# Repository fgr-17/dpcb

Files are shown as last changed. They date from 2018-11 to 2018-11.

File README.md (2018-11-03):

# VOP24_LPCXpresso1769_baseHW #

### autor: Ing. Roux Federico G. (rouxfederico@gmail.com) ###

Desarrollo en KICAD del hardware base para LPCXpresso1769 con los componentes básicos:

	- regulación de tensión digital y analógica.
	- ads1292
	- slot microSD
	- salida serie para BT
	- medición de batería

## Historial ##

27.06.2018:

	- Creación del repositorio
    - se inicio el esquematico con dos reg mc1702, micro sd y medicion de bateria con lm358
    ...
    - se agrego simbolo del lpcxpresso1769
    - falta acomodar los directorios de las librerias
    - falta ads1292, simbolo y footprint
    - falta footprint lpcxpresso1769

29.06.2018:

    - conexiones con la SD y lpc1796
    - falta ads1292, simbolo y footprint
    - falta footprint lpcxpresso1769

30.06.2018:

    - se agrego simbolo ads1292 al esquematico
    - falta terminar las conexiones del ads
    - conviene separar en modulos jerarq. -> VER COMO SE HACE

PENDIENTES:

- ver modelo del diodo schottky del L4411
- ver footprint del micro USB B - ver con lo q consiga
- definir inductor acoplado - HECHO
- intercambiar pines TPD_EN y USB_ID para que quede para rutear directo

02/11/2018 :

   - intercambiado pines TPD_EN y USB_ID para que quede para rutear directo
   - cambio de footprint de J303 y J302 por tira de pines de 2.54mm

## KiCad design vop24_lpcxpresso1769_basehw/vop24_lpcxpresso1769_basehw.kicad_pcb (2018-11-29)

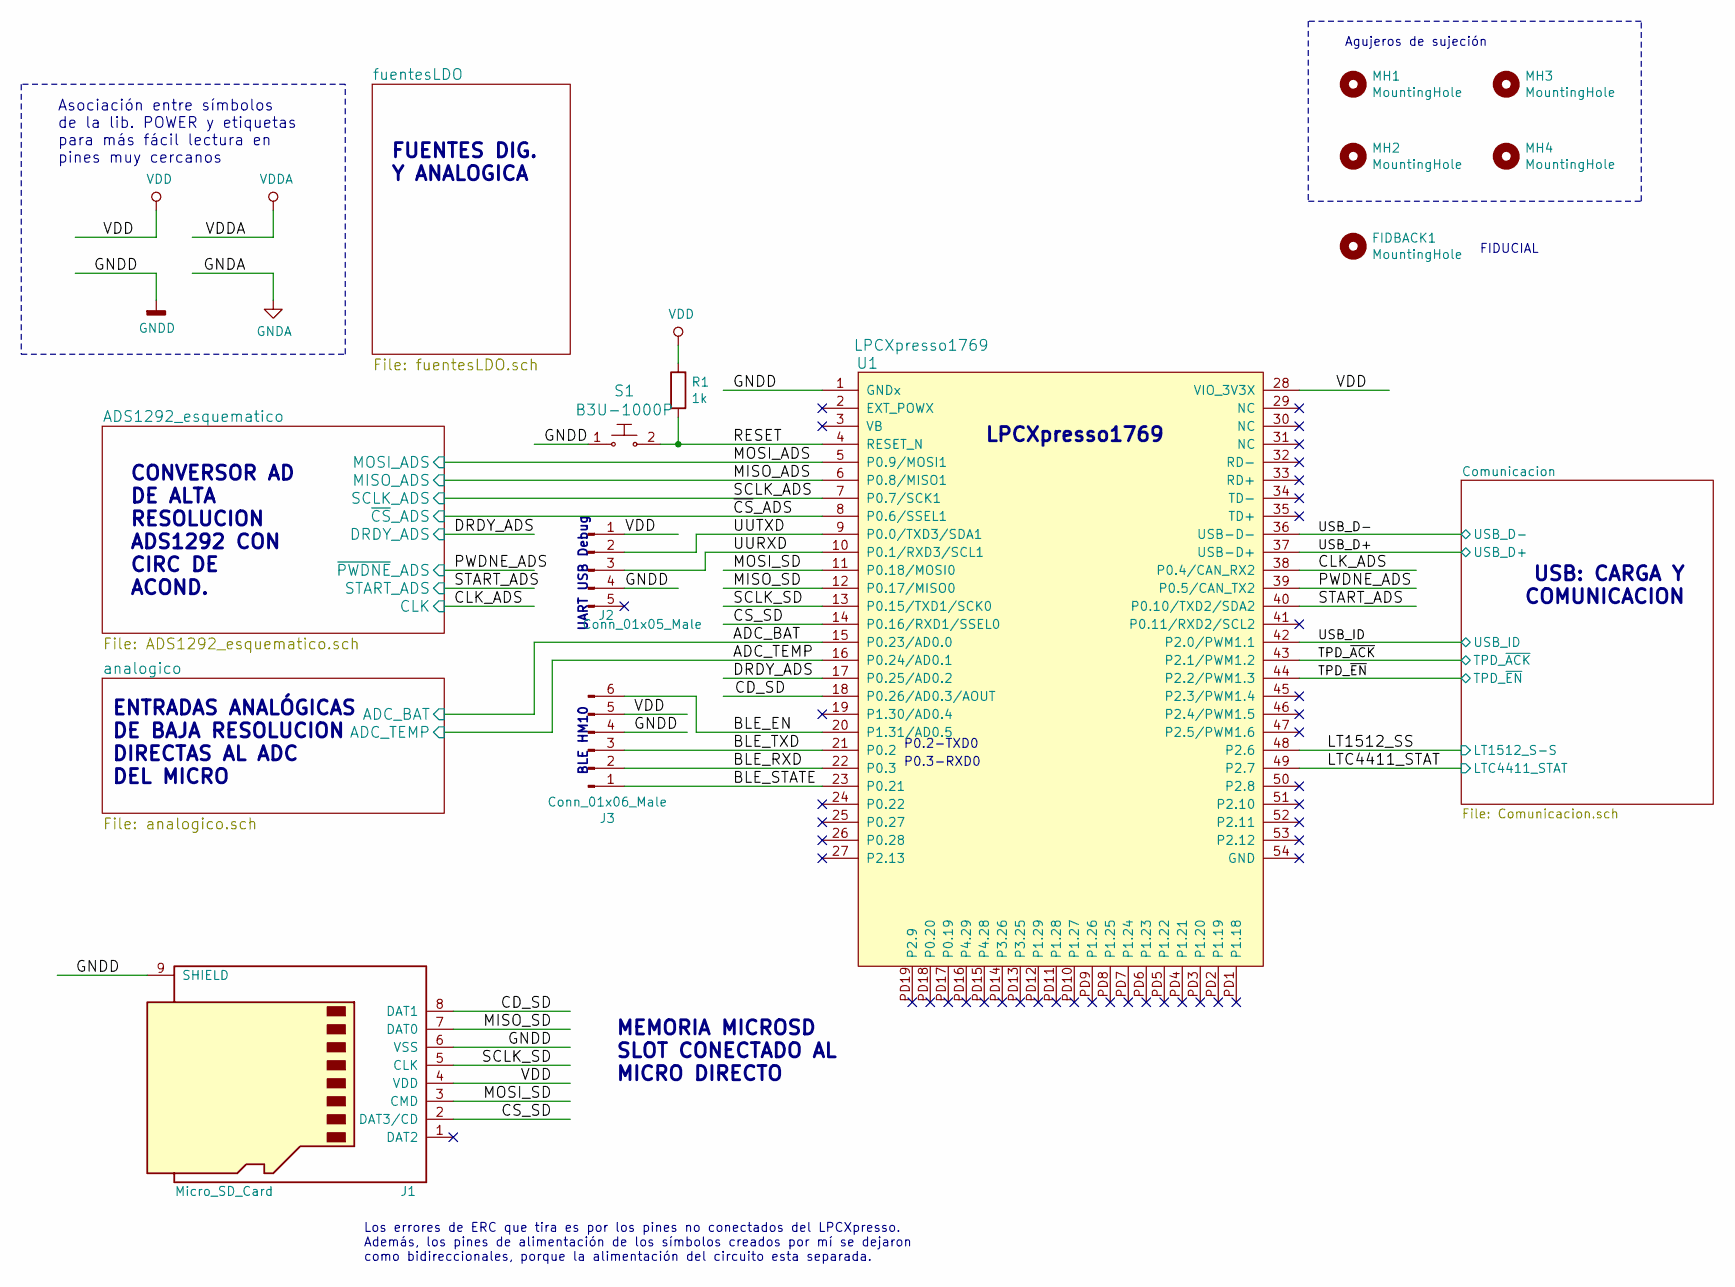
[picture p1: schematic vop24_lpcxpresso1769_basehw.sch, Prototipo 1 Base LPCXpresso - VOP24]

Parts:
FIDBACK1: MountingHole; Fiducial_0.75mm_Dia_1.5mm_Outer
J1: Micro_SD_Card; microSD_3020-901-0001-ACH-ELECTRONICS
J2: Conn_01x05_Male; PinSocket_1x05_P2.54mm_Vertical
J3: Conn_01x06_Male; PinSocket_1x06_P2.54mm_Vertical
MH1, MH2, MH3, MH4: MountingHole; MountingHole_3.5mm
R1: 1k; R_0805_2012Metric_Pad1.15x1.40mm_HandSolder
S1: B3U-1000P; Switch_Tactile_SMD_B3U-1000P; MPN B3U-1000P; Digi-Key_PN SW1020CT-ND
U1: LPCXpresso1769

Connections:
/ADC_BAT: U1.15 (P0.23/AD0.0); also elsewhere on the board
/ADC_TEMP: U1.16 (P0.24/AD0.1); also elsewhere on the board
/BLE_EN: J3.6, U1.20 (P1.31/AD0.5)
/BLE_RXD: J3.2, U1.22 (P0.3)
/BLE_STATE: J3.1, U1.23 (P0.21)
/BLE_TXD: J3.3, U1.21 (P0.2)
/CD_SD: J1.8 (DAT1), U1.18 (P0.26/AD0.3/AOUT)
/CLK_ADS: U1.38 (P0.4/CAN_RX2); also elsewhere on the board
/CS_SD: J1.2 (DAT3/CD), U1.14 (P0.16/RXD1/SSEL0)
/DRDY_ADS: U1.17 (P0.25/AD0.2); also elsewhere on the board
/LT1512_SS: U1.48 (P2.6); also elsewhere on the board
/LTC4411_STAT: U1.49 (P2.7); also elsewhere on the board
/MISO_ADS: U1.6 (P0.8/MISO1); also elsewhere on the board
/MISO_SD: J1.7 (DAT0), U1.12 (P0.17/MISO0)
/MOSI_ADS: U1.5 (P0.9/MOSI1); also elsewhere on the board
/MOSI_SD: J1.3 (CMD), U1.11 (P0.18/MOSI0)
/PWDNE_ADS: U1.39 (P0.5/CAN_TX2); also elsewhere on the board
/RESET: R1.2, S1.2, U1.4 (RESET_N)
/SCLK_ADS: U1.7 (P0.7/SCK1); also elsewhere on the board
/SCLK_SD: J1.5 (CLK), U1.13 (P0.15/TXD1/SCK0)
/START_ADS: U1.40 (P0.10/TXD2/SDA2); also elsewhere on the board
/TPD_~ACK: U1.43 (P2.1/PWM1.2); also elsewhere on the board
/TPD_~EN: U1.44 (P2.2/PWM1.3); also elsewhere on the board
/USB_D+: U1.37 (USB-D+); also elsewhere on the board
/USB_D-: U1.36 (USB-D-); also elsewhere on the board
/USB_ID: U1.42 (P2.0/PWM1.1); also elsewhere on the board
/UURXD: J2.3, U1.10 (P0.1/RXD3/SCL1)
/UUTXD: J2.2, U1.9 (P0.0/TXD3/SDA1)
/~CS~_ADS: U1.8 (P0.6/SSEL1); also elsewhere on the board
GNDD: J1.6 (VSS), J1.9 (SHIELD), J2.4, J3.4, S1.1, U1.1 (GNDx); also elsewhere on the board
VDD: J1.4 (VDD), J2.1, J3.5, R1.1, U1.28 (VIO_3V3X); also elsewhere on the board

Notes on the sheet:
P0.2-TXD0
P0.3-RXD0
FUENTES DIG. Y ANALOGICA
ENTRADAS ANALÓGICAS DE BAJA RESOLUCION DIRECTAS AL ADC DEL MICRO
MEMORIA MICROSD SLOT CONECTADO AL MICRO DIRECTO
USB: CARGA Y COMUNICACION
CONVERSOR AD DE ALTA RESOLUCION ADS1292 CON CIRC DE ACOND.
LPCXpresso1769
Los errores de ERC que tira es por los pines no conectados del LPCXpresso. Además, los pines de alimentación de los símbolos creados por mí se dejaron como bidireccionales, porque la alimentación del circuito esta separada.
BLE HM10
UART USB Debug
Asociación entre símbolos de la lib. POWER y etiquetas para más fácil lectura en pines muy cercanos
Agujeros de sujeción
FIDUCIAL

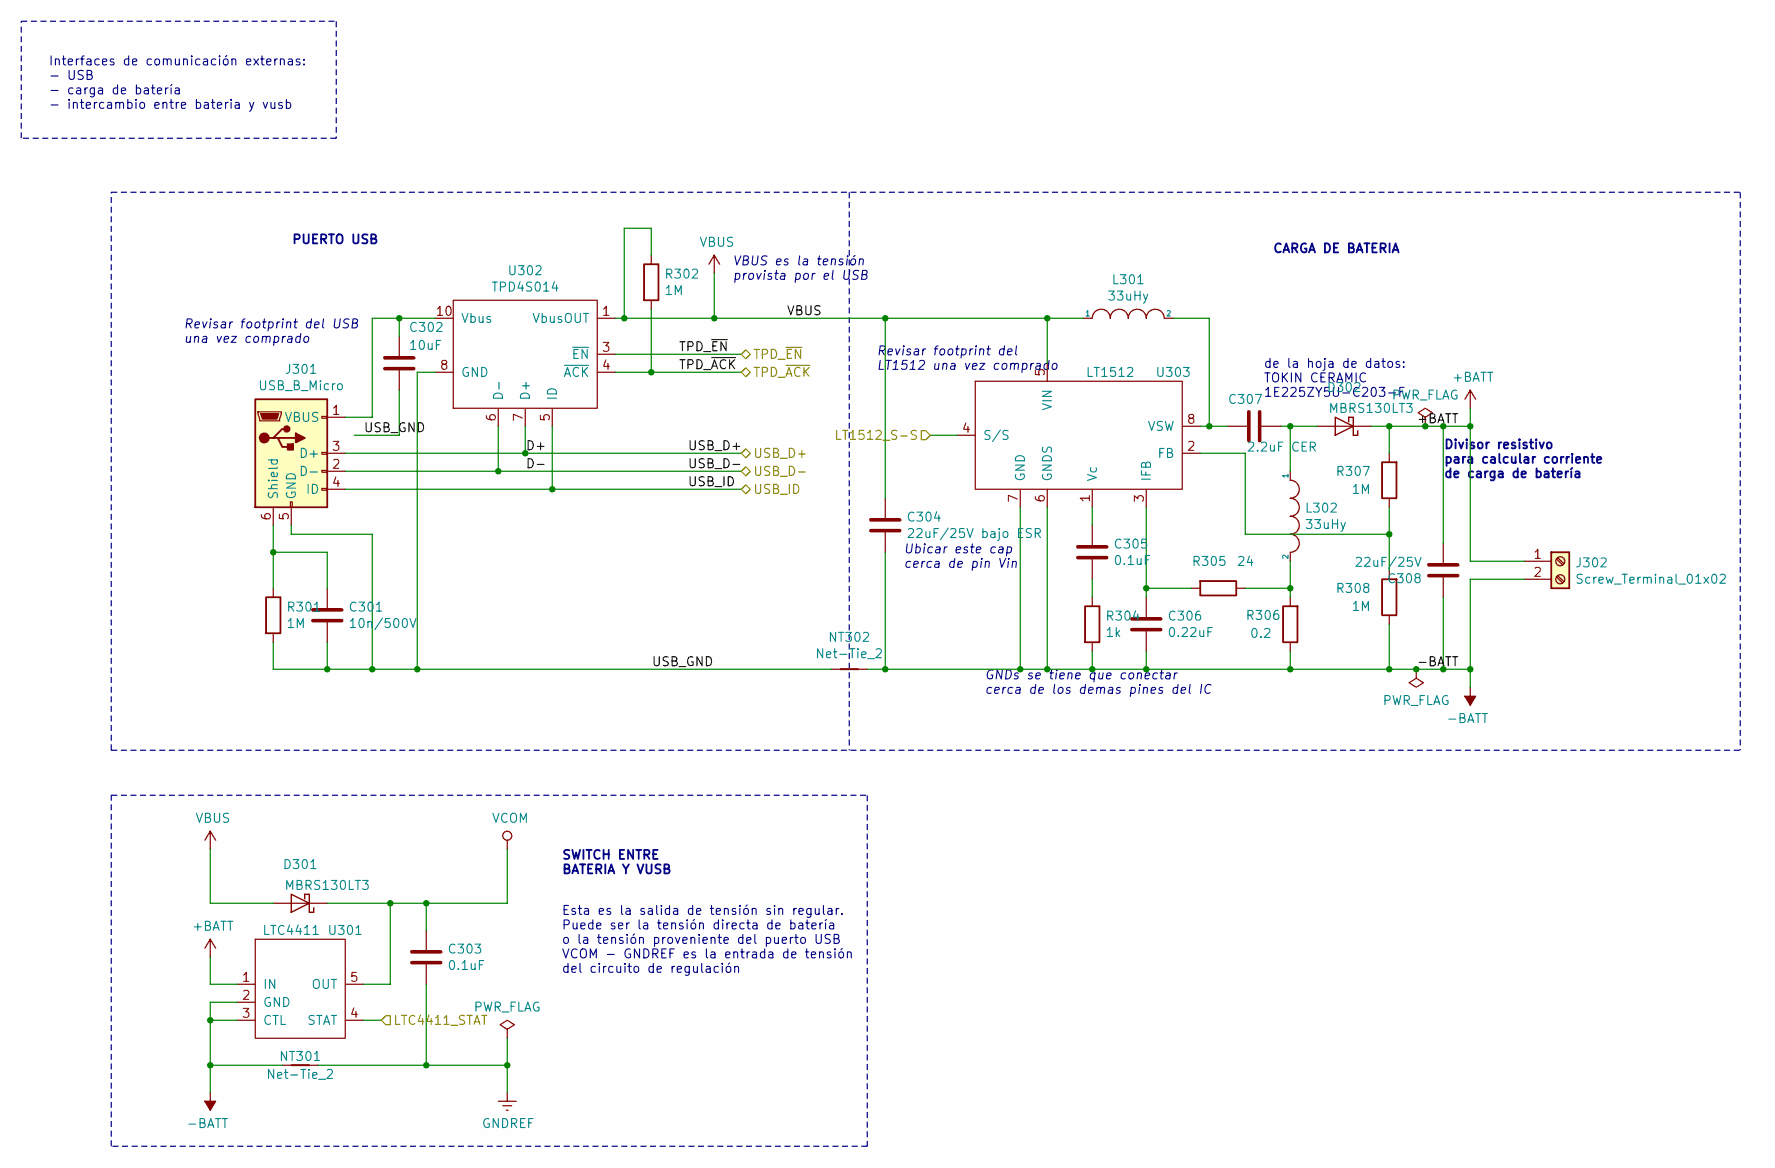
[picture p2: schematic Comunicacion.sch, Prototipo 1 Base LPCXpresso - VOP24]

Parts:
C301: 10n/500V; C_0805_2012Metric_Pad1.15x1.40mm_HandSolder
C302: 10uF; C_0805_2012Metric_Pad1.15x1.40mm_HandSolder
C303, C305: 0.1uF; C_0805_2012Metric_Pad1.15x1.40mm_HandSolder
C304: 22uF/25V bajo ESR; CP_Radial_D5.0mm_P2.50mm
C306: 0.22uF; C_0805_2012Metric_Pad1.15x1.40mm_HandSolder
C307: 2.2uF CER; CP_Radial_D5.0mm_P2.50mm
C308: 22uF/25V; CP_Radial_D5.0mm_P2.50mm
D301, D302: MBRS130LT3; D_SMB-SMC_Universal_Handsoldering
J301: USB_B_Micro; USB_Mini-B_Lumberg_2486_01_Horizontal
J302: Screw_Terminal_01x02; TerminalBlock_bornier-2_P5.08mm
L301, L302: 33uHy; L_Radial_D8.7mm_P5.00mm_Fastron_07HCP
NT301, NT302: Net-Tie_2; NetTie-2_SMD_Pad0.5mm
R301, R302, R307, R308: 1M; R_0805_2012Metric_Pad1.15x1.40mm_HandSolder
R304: 1k; R_0805_2012Metric_Pad1.15x1.40mm_HandSolder
R305: 24; R_0805_2012Metric_Pad1.15x1.40mm_HandSolder
R306: 0.2; R_0805_2012Metric_Pad1.15x1.40mm_HandSolder
U301: LTC4411; SOT-23-5_HandSoldering
U302: TPD4S014; Texas_R-PWSON-N10
U303: LT1512; SO-8_5.3x6.2mm_P1.27mm

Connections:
+BATT: C308.2, D302.1 (K), J302.1, R307.2, U301.1 (IN); also elsewhere on the board
-BATT: C304.2, C306.2, C308.1, J302.2, NT301.1, NT302.2, R304.2, R306.1, R308.1, U301.2 (GND), U301.3 (CTL), U303.6 (GNDS), U303.7 (GND); also elsewhere on the board
/Comunicacion/USB_GND: C301.2, C302.2, J301.5 (GND), NT302.1, R301.2, U302.8 (GND)
/LT1512_SS: U303.4 (S/S); also elsewhere on the board
/LTC4411_STAT: U301.4 (STAT); also elsewhere on the board
/TPD_~ACK: R302.2, U302.4 (~ACK); also elsewhere on the board
/TPD_~EN: U302.3 (~EN); also elsewhere on the board
/USB_D+: J301.3 (D+), U302.7 (D+); also elsewhere on the board
/USB_D-: J301.2 (D-), U302.6 (D-); also elsewhere on the board
/USB_ID: J301.4 (ID), U302.5 (ID); also elsewhere on the board
GNDREF: C303.2, NT301.2; also elsewhere on the board
unnamed: C301.1, J301.6 (Shield), R301.1
unnamed: C302.1, J301.1 (VBUS), U302.10 (Vbus)
unnamed: C305.1, U303.1 (Vc)
unnamed: C305.2, R304.1
unnamed: C306.1, R305.2, U303.3 (IFB)
unnamed: C307.1, D302.2 (A), L302.1
unnamed: C307.2, L301.2, U303.8 (VSW)
unnamed: L302.2, R305.1, R306.2
unnamed: R307.1, R308.2, U303.2 (FB)
VBUS: C304.1, D301.2 (A), L301.1, R302.1, U302.1 (VbusOUT), U303.5 (VIN)
VCOM: C303.1, D301.1 (K), U301.5 (OUT); also elsewhere on the board

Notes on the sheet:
de la hoja de datos: TOKIN CERAMIC 1E225ZY5U-C203-F
Divisor resistivo para calcular corriente de carga de batería
CARGA DE BATERIA
SWITCH ENTRE BATERIA Y VUSB
PUERTO USB
Revisar footprint del USB una vez comprado
Revisar footprint del LT1512 una vez comprado
Ubicar este cap cerca de pin Vin
GNDs se tiene que conectar cerca de los demas pines del IC
Interfaces de comunicación externas: - USB - carga de batería - intercambio entre bateria y vusb
Esta es la salida de tensión sin regular. Puede ser la tensión directa de batería o la tensión proveniente del puerto USB VCOM - GNDREF es la entrada de tensión del circuito de regulación
VBUS es la tensión provista por el USB

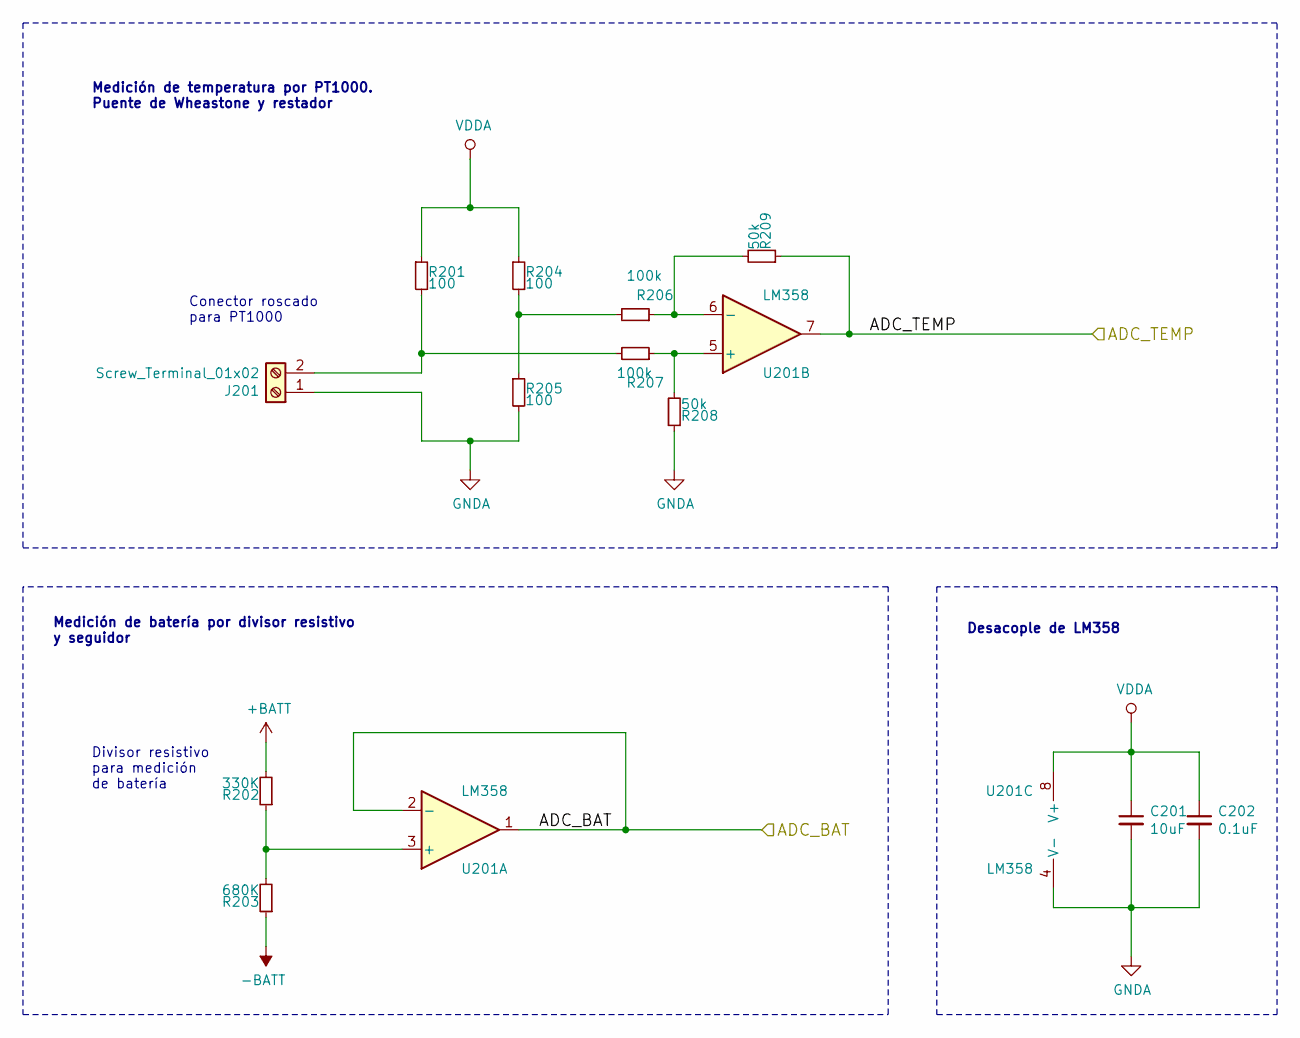
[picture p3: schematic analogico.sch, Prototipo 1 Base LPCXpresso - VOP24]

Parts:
C201: 10uF; C_0805_2012Metric_Pad1.15x1.40mm_HandSolder
C202: 0.1uF; C_0805_2012Metric_Pad1.15x1.40mm_HandSolder
J201: Screw_Terminal_01x02; TerminalBlock_bornier-2_P5.08mm
R201, R204, R205: 100; R_0805_2012Metric_Pad1.15x1.40mm_HandSolder
R202: 330K; R_0805_2012Metric_Pad1.15x1.40mm_HandSolder
R203: 680K; R_0805_2012Metric_Pad1.15x1.40mm_HandSolder
R206, R207: 100k; R_0805_2012Metric_Pad1.15x1.40mm_HandSolder
R208, R209: 50k; R_0805_2012Metric_Pad1.15x1.40mm_HandSolder
U201: LM358; SO-8_5.3x6.2mm_P1.27mm

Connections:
+BATT: R202.2; also elsewhere on the board
-BATT: R203.1; also elsewhere on the board
/ADC_BAT: U201.1, U201.2 (-); also elsewhere on the board
/ADC_TEMP: R209.1, U201.7; also elsewhere on the board
GNDA: C201.2, C202.2, J201.1, R205.2, R208.1, U201.4 (V-); also elsewhere on the board
unnamed: J201.2, R201.2, R207.2
unnamed: R202.1, R203.2, U201.3 (+)
unnamed: R204.2, R205.1, R206.2
unnamed: R206.1, R209.2, U201.6 (-)
unnamed: R207.1, R208.2, U201.5 (+)
VDDA: C201.1, C202.1, R201.1, R204.1, U201.8 (V+); also elsewhere on the board

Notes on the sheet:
Conector roscado para PT1000
Divisor resistivo para medición de batería
Medición de temperatura por PT1000. Puente de Wheastone y restador
Medición de batería por divisor resistivo y seguidor
Desacople de LM358

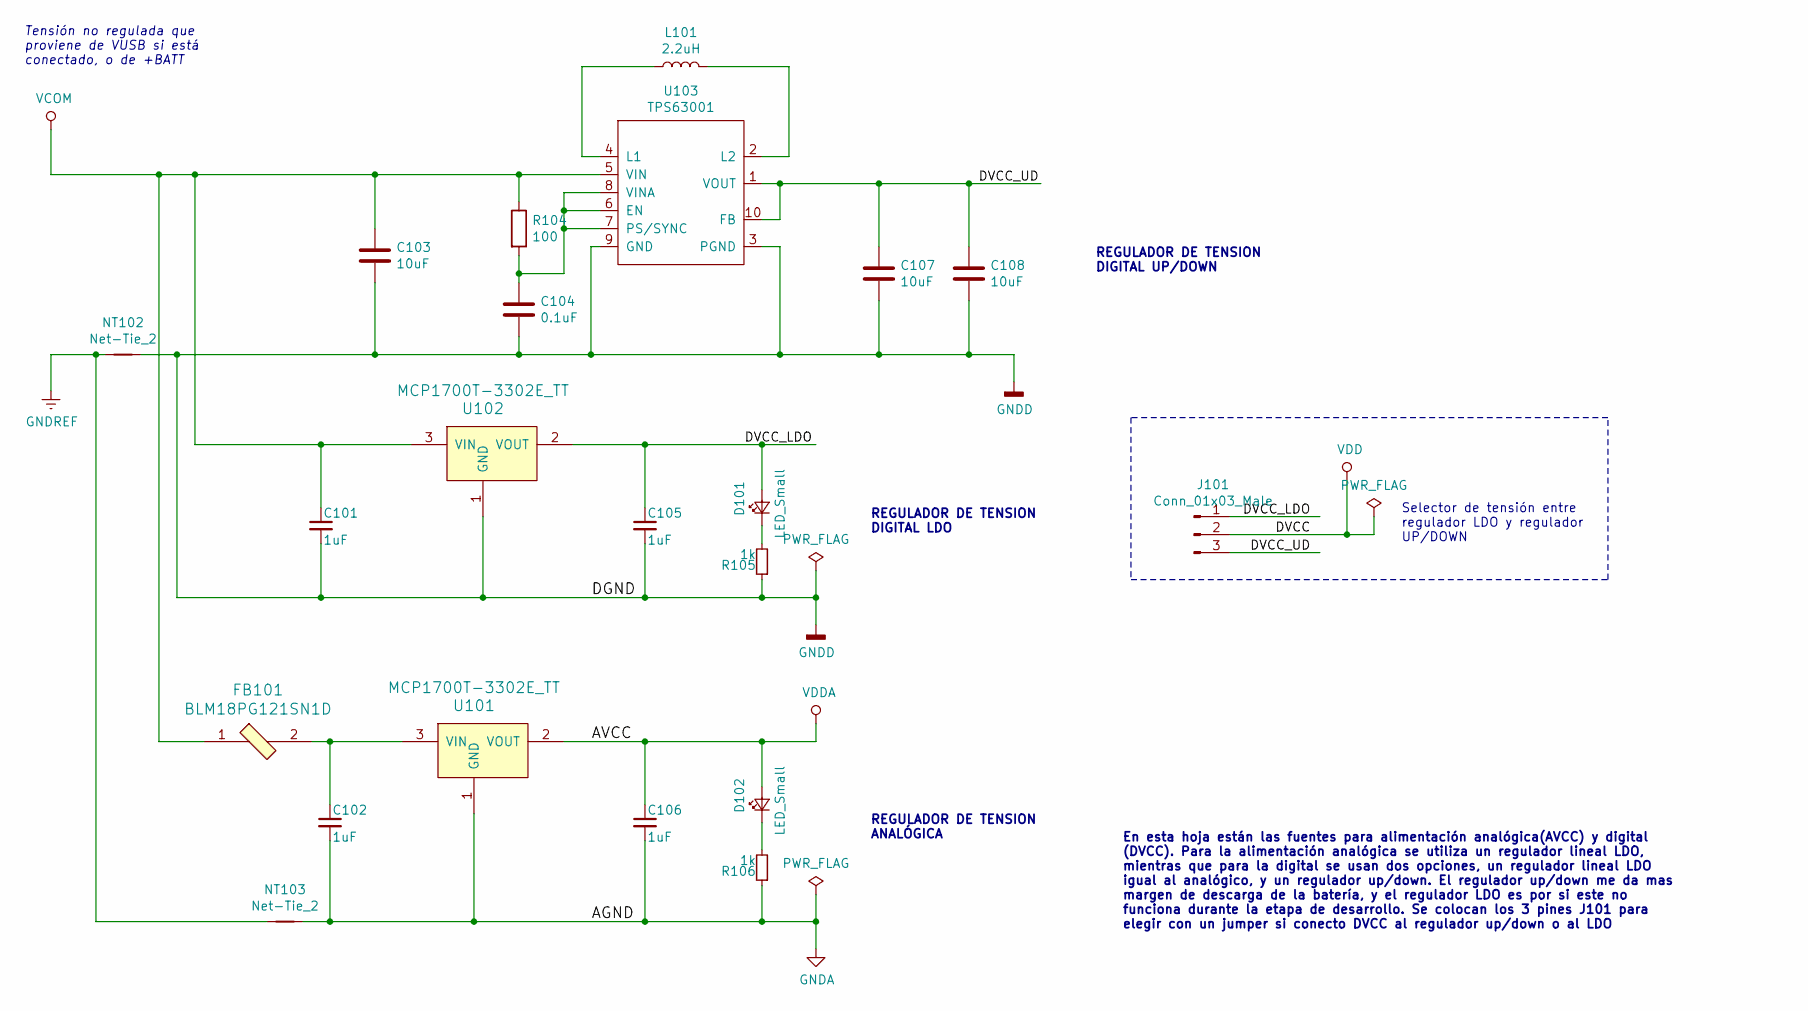
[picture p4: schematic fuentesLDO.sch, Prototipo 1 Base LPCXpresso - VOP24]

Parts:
C101, C102, C105, C106: 1uF; C_0805_2012Metric_Pad1.15x1.40mm_HandSolder
C103, C107, C108: 10uF; C_0805_2012Metric_Pad1.15x1.40mm_HandSolder
C104: 0.1uF; C_0805_2012Metric_Pad1.15x1.40mm_HandSolder
D101, D102: LED_Small; LED_0805_2012Metric_Pad1.15x1.40mm_HandSolder
FB101: BLM18PG121SN1D; 0603; MPN BLM18PG121SN1D; Digi-Key_PN 490-1037-1-ND
J101: Conn_01x03_Male; PinHeader_1x03_P2.54mm_Vertical
L101: 2.2uH; L_0805_2012Metric_Pad1.15x1.40mm_HandSolder
NT102, NT103: Net-Tie_2; NetTie-2_SMD_Pad0.5mm
R104: 100; R_0805_2012Metric_Pad1.15x1.40mm_HandSolder
R105, R106: 1k; R_0805_2012Metric_Pad1.15x1.40mm_HandSolder
U101, U102: MCP1700T-3302E_TT; SOT-23-3; MPN MCP1700T-3302E/TT; Digi-Key_PN MCP1700T3302ETTCT-ND
U103: TPS63001; VSON-10-1EP_3x3mm_P0.5mm_EP1.65x2.4mm_ThermalVias

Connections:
/fuentesLDO/DVCC_LDO: C105.1, D101.2 (A), J101.1, U102.2 (VOUT)
/fuentesLDO/DVCC_UD: C107.1, C108.1, J101.3, U103.1 (VOUT), U103.10 (FB)
GNDA: C102.2, C106.2, NT103.2, R106.1, U101.1 (GND); also elsewhere on the board
GNDD: C101.2, C103.2, C104.2, C105.2, C107.2, C108.2, NT102.2, R105.1, U102.1 (GND), U103.3 (PGND), U103.9 (GND); also elsewhere on the board
GNDREF: NT102.1, NT103.1; also elsewhere on the board
unnamed: C102.1, FB101.2, U101.3 (VIN)
unnamed: C104.1, R104.2, U103.6 (EN), U103.7 (PS/SYNC), U103.8 (VINA)
unnamed: D101.1 (K), R105.2
unnamed: D102.1 (K), R106.2
unnamed: L101.1, U103.4 (L1)
unnamed: L101.2, U103.2 (L2)
VCOM: C101.1, C103.1, FB101.1, R104.1, U102.3 (VIN), U103.5 (VIN); also elsewhere on the board
VDD: J101.2; also elsewhere on the board
VDDA: C106.1, D102.2 (A), U101.2 (VOUT); also elsewhere on the board

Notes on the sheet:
En esta hoja están las fuentes para alimentación analógica(AVCC) y digital (DVCC). Para la alimentación analógica se utiliza un regulador lineal LDO, mientras que para la digital se usan dos opciones, un regulador lineal LDO igual al analógico, y un regulador up/down. El regulador up/down me da mas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
Tensión no regulada que proviene de VUSB si está conectado, o de +BATT
REGULADOR DE TENSION ANALÓGICA
REGULADOR DE TENSION DIGITAL LDO
REGULADOR DE TENSION DIGITAL UP/DOWN
Selector de tensión entre regulador LDO y regulador UP/DOWN

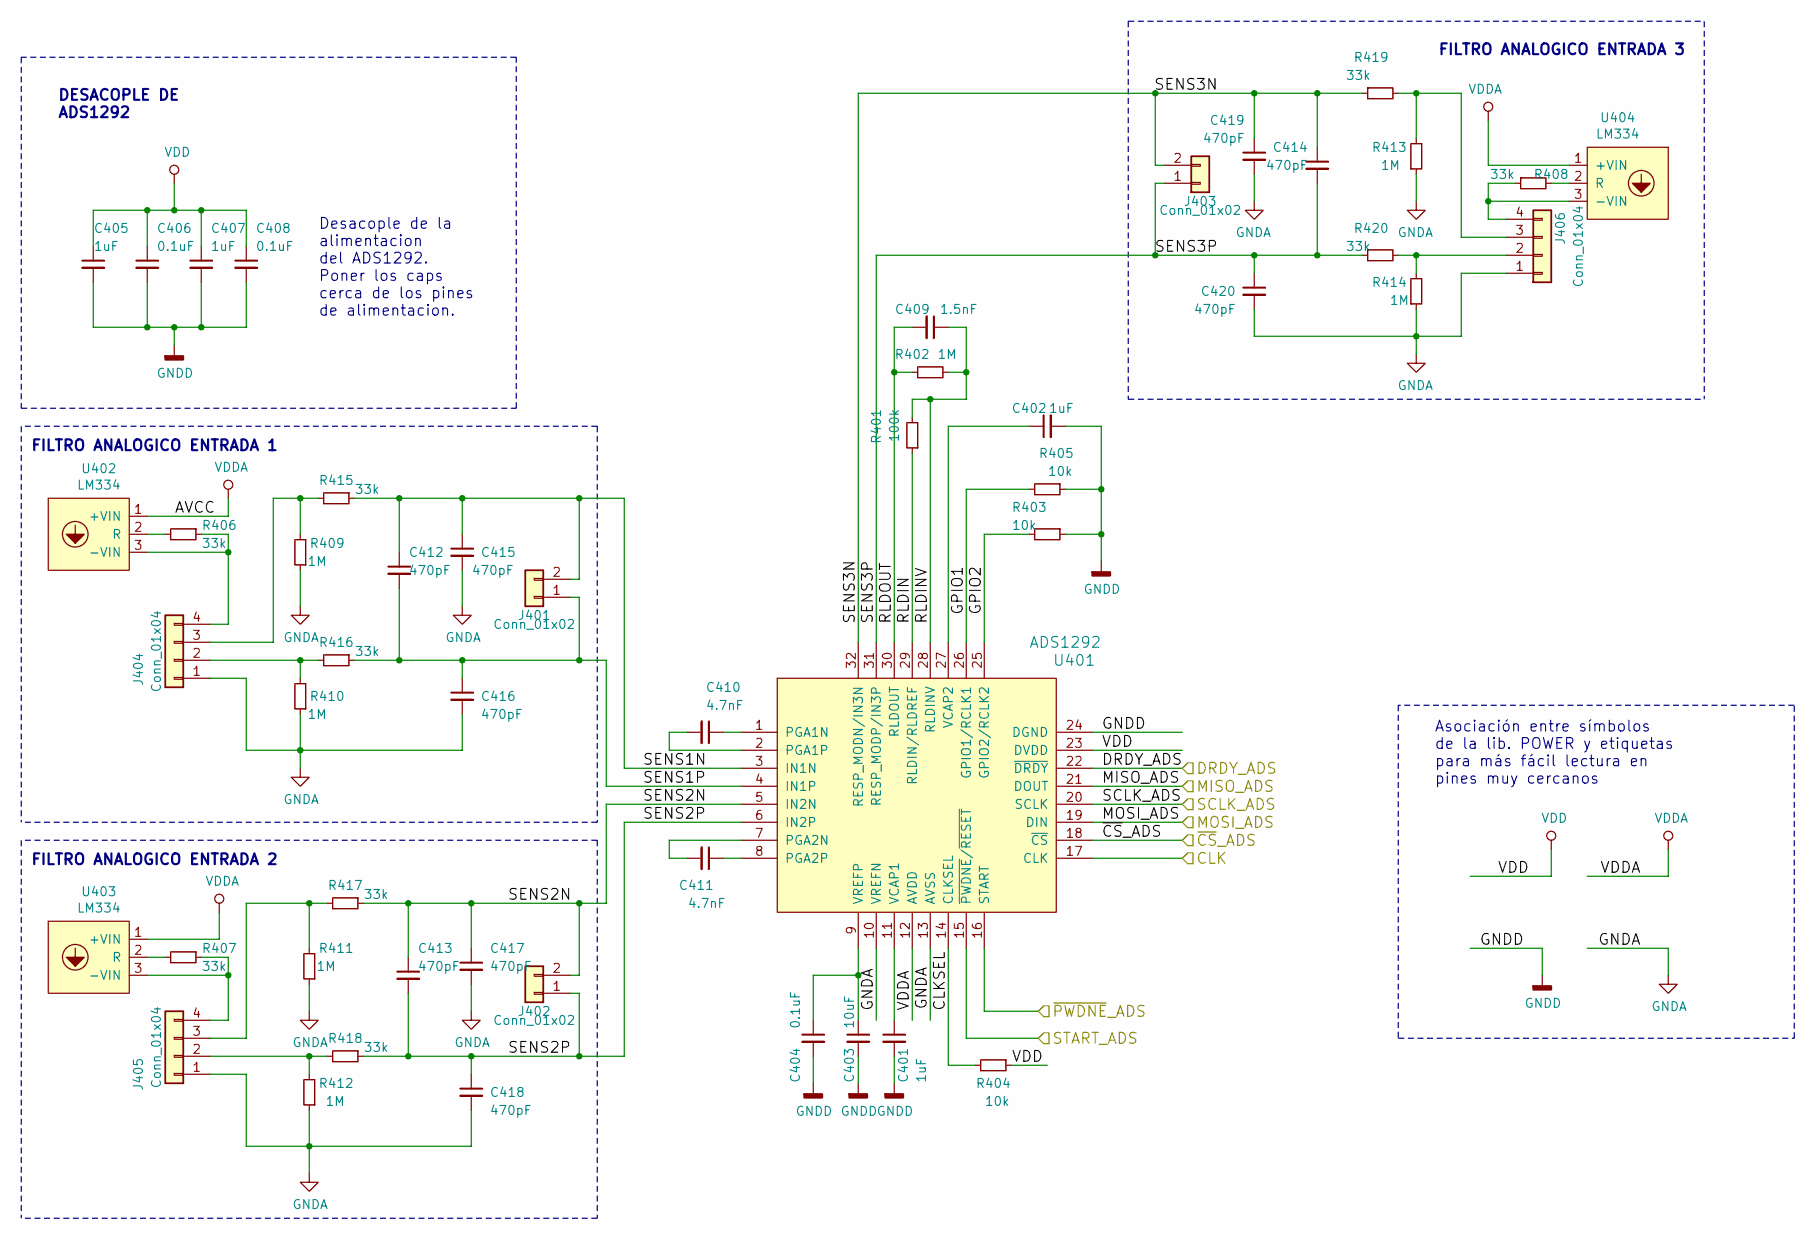
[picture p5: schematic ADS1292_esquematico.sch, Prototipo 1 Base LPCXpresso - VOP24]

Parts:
C401, C402, C405, C407: 1uF; C_0805_2012Metric_Pad1.15x1.40mm_HandSolder
C403: 10uF; C_0805_2012Metric_Pad1.15x1.40mm_HandSolder
C404, C406, C408: 0.1uF; C_0805_2012Metric_Pad1.15x1.40mm_HandSolder
C409: 1.5nF; C_0805_2012Metric_Pad1.15x1.40mm_HandSolder
C410, C411: 4.7nF; C_0805_2012Metric_Pad1.15x1.40mm_HandSolder
C412, C413, C414, C415, C416, C417, C418, C419, C420: 470pF; C_0805_2012Metric_Pad1.15x1.40mm_HandSolder
J401, J402, J403: Conn_01x02; PinHeader_1x02_P1.27mm_Vertical
J404, J405, J406: Conn_01x04; PinSocket_1x04_P2.54mm_Vertical
R401: 100k; R_0805_2012Metric_Pad1.15x1.40mm_HandSolder
R402, R409, R410, R411, R412, R413, R414: 1M; R_0805_2012Metric_Pad1.15x1.40mm_HandSolder
R403, R404, R405: 10k; R_0805_2012Metric_Pad1.15x1.40mm_HandSolder
R406, R407, R408, R415, R416, R417, R418, R419, R420: 33k; R_0805_2012Metric_Pad1.15x1.40mm_HandSolder
U401: ADS1292; PQFP-G32_7x7mm_P0.5mm
U402, U403, U404: LM334; TO-92_Inline_Wide

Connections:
/ADS1292_esquematico/CLKSEL: R404.2, U401.14 (CLKSEL)
/ADS1292_esquematico/GPIO1: R405.2, U401.26 (GPIO1/RCLK1)
/ADS1292_esquematico/GPIO2: R403.2, U401.25 (GPIO2/RCLK2)
/ADS1292_esquematico/RLDIN: R401.1, U401.29 (RLDIN/RLDREF)
/ADS1292_esquematico/RLDINV: C409.1, R401.2, R402.2, U401.28 (RLDINV)
/ADS1292_esquematico/RLDOUT: C409.2, R402.1, U401.30 (RLDOUT)
/ADS1292_esquematico/SENS1N: C412.1, C415.1, J401.2, R415.1, U401.3 (IN1N)
/ADS1292_esquematico/SENS1P: C412.2, C416.1, J401.1, R416.1, U401.4 (IN1P)
/ADS1292_esquematico/SENS2N: C413.1, C417.1, J402.2, R417.1, U401.5 (IN2N)
/ADS1292_esquematico/SENS2P: C413.2, C418.1, J402.1, R418.1, U401.6 (IN2P)
/ADS1292_esquematico/SENS3N: C414.1, C419.1, J403.2, R419.1, U401.32 (RESP_MODN/IN3N)
/ADS1292_esquematico/SENS3P: C414.2, C420.1, J403.1, R420.1, U401.31 (RESP_MODP/IN3P)
/CLK_ADS: U401.17 (CLK); also elsewhere on the board
/DRDY_ADS: U401.22 (~DRDY); also elsewhere on the board
/MISO_ADS: U401.21 (DOUT); also elsewhere on the board
/MOSI_ADS: U401.19 (DIN); also elsewhere on the board
/PWDNE_ADS: U401.16 (START); also elsewhere on the board
/SCLK_ADS: U401.20 (SCLK); also elsewhere on the board
/START_ADS: U401.15 (~PWDNE~/~RESET~); also elsewhere on the board
/~CS~_ADS: U401.18 (~CS); also elsewhere on the board
GNDA: C415.2, C416.2, C417.2, C418.2, C419.2, C420.2, J404.1, J405.1, J406.1, R409.1, R410.1, R411.1, R412.1, R413.1, R414.1, U401.10 (VREFN), U401.13 (AVSS); also elsewhere on the board
GNDD: C401.2, C402.2, C403.2, C404.2, C405.2, C406.2, C407.2, C408.2, R403.1, R405.1, U401.24 (DGND); also elsewhere on the board
unnamed: C401.1, U401.11 (VCAP1)
unnamed: C402.1, U401.27 (VCAP2)
unnamed: C403.1, C404.1, U401.9 (VREFP)
unnamed: C410.1, U401.1 (PGA1N)
unnamed: C410.2, U401.2 (PGA1P)
unnamed: C411.1, U401.8 (PGA2P)
unnamed: C411.2, U401.7 (PGA2N)
unnamed: J404.2, R410.2, R416.2
unnamed: J404.3, R409.2, R415.2
unnamed: J404.4, R406.1, U402.3 (-VIN)
unnamed: J405.2, R412.2, R418.2
unnamed: J405.3, R411.2, R417.2
unnamed: J405.4, R407.1, U403.3 (-VIN)
unnamed: J406.2, R414.2, R420.2
unnamed: J406.3, R413.2, R419.2
unnamed: J406.4, R408.1, U404.3 (-VIN)
unnamed: R406.2, U402.2 (R)
unnamed: R407.2, U403.2 (R)
unnamed: R408.2, U404.2 (R)
VDD: C405.1, C406.1, C407.1, C408.1, R404.1, U401.23 (DVDD); also elsewhere on the board
VDDA: U401.12 (AVDD), U402.1 (+VIN), U403.1 (+VIN), U404.1 (+VIN); also elsewhere on the board

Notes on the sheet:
FILTRO ANALOGICO ENTRADA 1
FILTRO ANALOGICO ENTRADA 2
FILTRO ANALOGICO ENTRADA 3
Desacople de la alimentacion del ADS1292. Poner los caps cerca de los pines de alimentacion.
DESACOPLE DE ADS1292
Asociación entre símbolos de la lib. POWER y etiquetas para más fácil lectura en pines muy cercanos

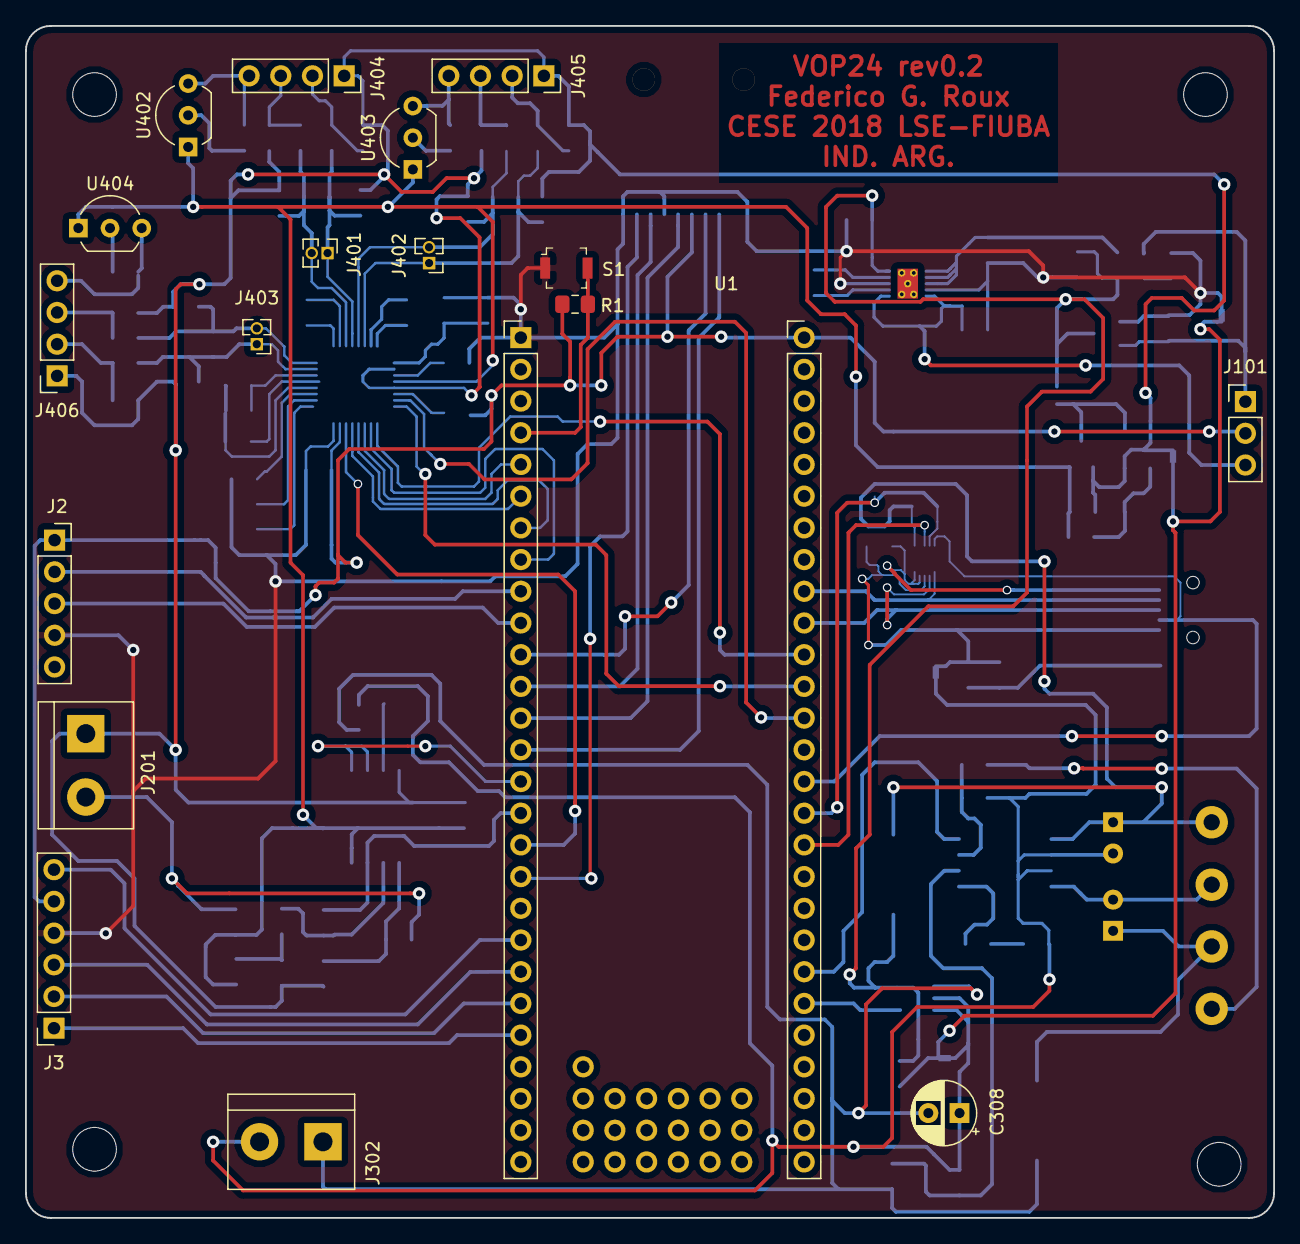
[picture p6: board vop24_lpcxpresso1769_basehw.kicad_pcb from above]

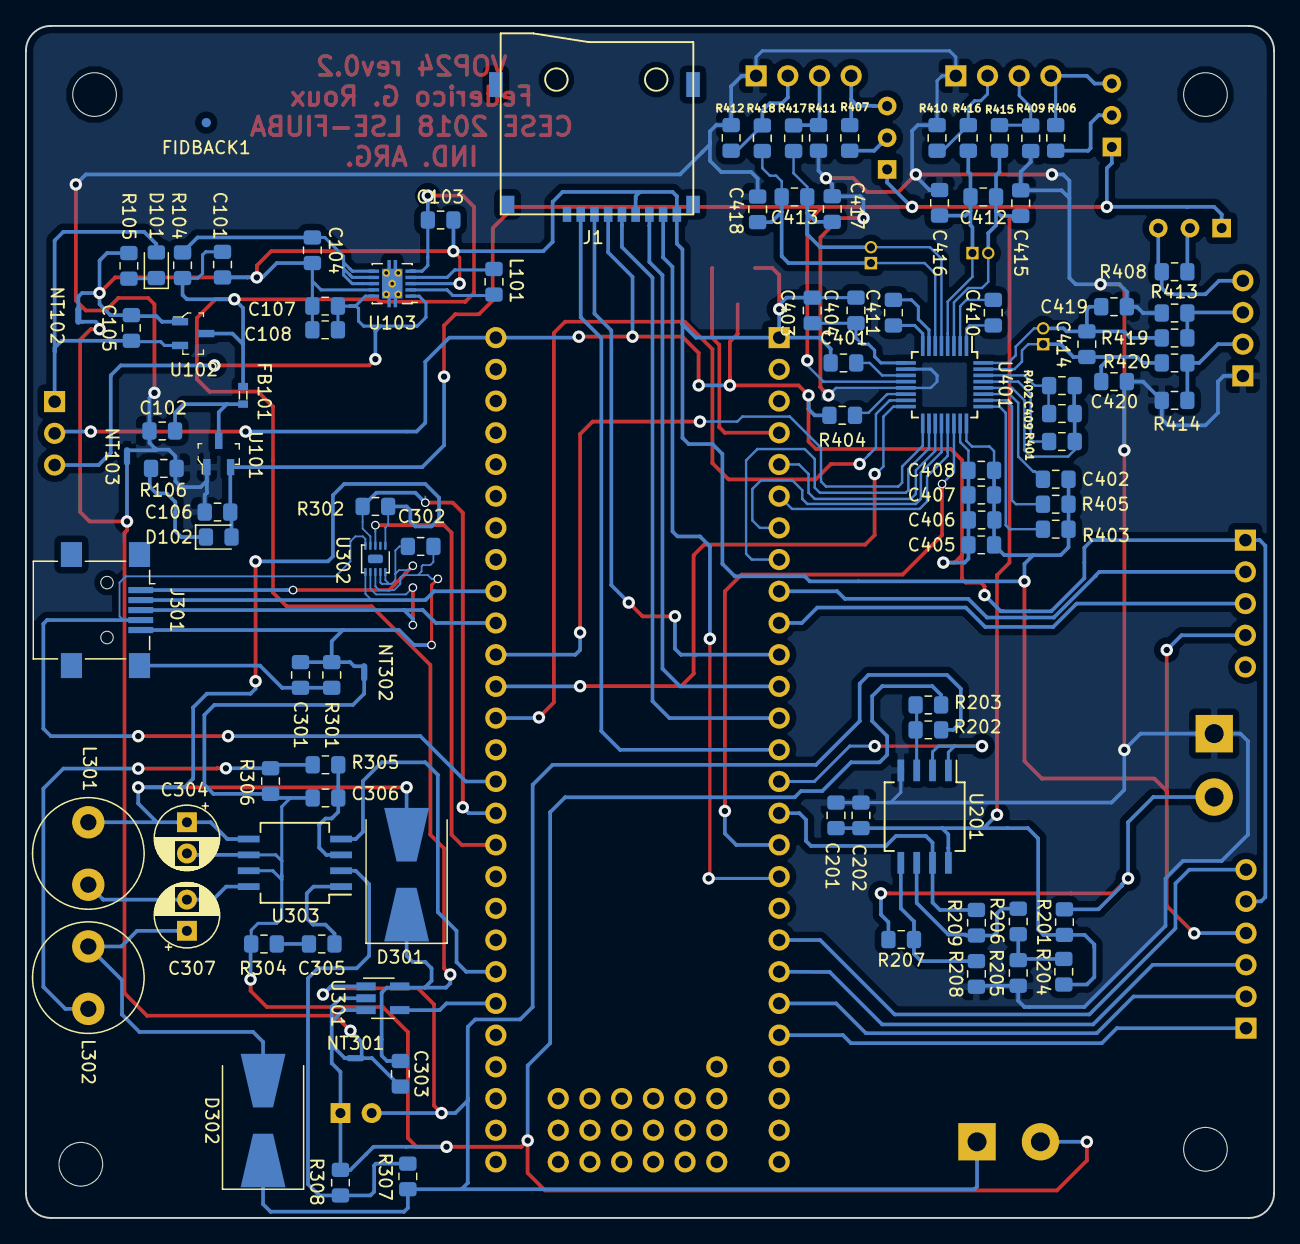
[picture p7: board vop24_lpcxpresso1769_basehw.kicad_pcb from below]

Board: 2 copper layers, 100.0 x 95.5 mm, 121 parts (99 on the bottom side), 92 nets.

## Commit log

2018-06-27 Inicio de esquematico con partes ppales. Falta completar y hacer simbolo y footprint de LPCXpresso1769
    [vop24_lpcxpresso1769_basehw.kicad_pcb, vop24_lpcxpresso1769_basehw.sch]
2018-06-28 Esquematico: - se agrego simbolo lpcxpresso1769
    [vop24_lpcxpresso1769_basehw.sch]
2018-06-30 Esquematico: - conexion SD con lpc1769
    [vop24_lpcxpresso1769_basehw.sch]
2018-06-30 Esquematico: - ads1292 con conexiones parcial
    [vop24_lpcxpresso1769_basehw.sch]
2018-07-01 Esquematico: - se paso el circuito de fuentes a una hoja aparte - falta pasar todas las demas a hojas separadas - terminar conexiones del ads - poner desacoples de alimentacion para cada IC - ver com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
    [fuentesLDO.sch, vop24_lpcxpresso1769_basehw.sch]
2018-07-04 Esquematico: agregados hojas separadas de entradas analogicas terminadas y ads1292 sin terminar
    [ADS1292_esquematico.sch, analogico.sch, fuentesLDO.sch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]
2018-07-08 Esquematico: - terminar conexiones de ads: revisar slau387.pdf para conexiones de caps y bobinas - ver slau387.pdf para medicion de fuente y conexion usb
    [ADS1292_esquematico.sch, analogico.sch, fuentesLDO.sch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]
2018-07-09 Esquematico ADS1292: - invertir valor y nombre de todas las resistencias (puse el valor en el campo nombre :( ) - agregar protecciones y desacoples como en la nota de aplicacion - terminar filtros an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
    [ADS1292_esquematico.sch]
2018-07-11 Esquematico ADS: - version a revisar. Falta agregar medicion de bateria y carga USB como en la nota de aplicacion
    [ADS1292_esquematico.sch, vop24_lpcxpresso1769_basehw.sch]
2018-09-18 Esquematico Comunicacion: falta agregar USB, BLE y UART
    [ADS1292_esquematico-2018-08-04-11-07-02.sch, ADS1292_esquematico.sch, Comunicacion.sch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]
2018-09-28 Esq Comunicacion: USB, BLE y UART resueltos. Falta ver control de alimentación de BLE en caso que no se pueda apagar
    [Comunicacion.sch, _saved_Comunicacion.sch]
2018-10-12 Primera versión esquematico sin revisar
    [ADS1292_esquematico.sch, Carga_Bateria.sch, Comunicacion.sch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]
2018-10-20 Algunas correcciones sobre el esquemático. Falta terminar de revisar algunos conflictos del DRC
    [ADS1292_esquematico.sch, Comunicacion.sch, analogico.sch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]
2018-10-26 Correcciones de esquemático: - resueltos todos los conflictos de DRC - cambio de circutio de medicion de temp - ordenados todas las etiquetas y valores
    [ADS1292_esquematico.sch, Comunicacion.sch, analogico.sch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]
2018-10-27 Se agregaron la mayoría de los footprints de los ICs
    [ADS1292_esquematico.sch, Comunicacion.sch, analogico.sch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]
2018-11-01 Finalizada asociación de todos los footprints. Ver librerías froux-kicad
    [ADS1292_esquematico.sch, Comunicacion.sch, _saved_Comunicacion.sch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]
2018-11-03 Primer commit sobre el diseño del PCB. Se agruparon algunas hojas de esquemáticos. No se empezó a rutear
    [Comunicacion.sch, _saved_Comunicacion.sch, vop24_lpcxpresso1769_basehw.sch]
2018-11-11 PCB: componentes agrupados por zona
    [ADS1292_esquematico.sch, vop24_lpcxpresso1769_basehw.kicad_pcb]
2018-11-11 Cambios menores en circuito ADS
    [vop24_lpcxpresso1769_basehw.kicad_pcb]
2018-11-12 PCB: posicionamiento preruteo. ESQ: cambio de footprint de conectores
    [ADS1292_esquematico.sch, Comunicacion.sch, _saved_ADS1292_esquematico.sch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]
2018-11-13 PCB: ruteo e ubicacion de USB. ESQ: cambios de etiquetas de gnd en usb
    [ADS1292_esquematico.sch, Comunicacion.sch, _saved_ADS1292_esquematico.sch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]
2018-11-13 PCB: progreso en el ruteo
    [vop24_lpcxpresso1769_basehw.kicad_pcb]
2018-11-14 PCB: ruteo de fuentes. SCH: separacion de pistas de masa en fuentes
    [Comunicacion.sch, analogico.sch, fuentesLDO.sch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]
2018-11-14 PCB: primera versión de ruteo finalizado sin poligonos. SCH: cambios de conexiones para facilitar conexiones
    [vop24_lpcxpresso1769_basehw.kicad_pcb, vop24_lpcxpresso1769_basehw.sch]
2018-11-14 PCB: ruteo finalizado con polígonos y texto en F.Cu. Agujeros en esquinas SCH: sin cambios
    [vop24_lpcxpresso1769_basehw.kicad_pcb]
2018-11-14 PCB: agregado de leyenda de nombre de placa y revisión
    [vop24_lpcxpresso1769_basehw.kicad_pcb]
2018-11-15 Agregado de leyendas en PCB y ESQ. Agregado de cotas en PCB
    [ADS1292_esquematico.sch, Comunicacion.sch, analogico.sch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]
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2018-11-23 ESQ: modificaciones de etiquetas. Falta cambiar todas las conexiones de vcc
    [ADS1292_esquematico.sch, Comunicacion.sch, analogico.sch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]
2018-11-25 ESQ: cambios sobre etiquetas y simbolos de POWER
    [ADS1292_esquematico.sch, Comunicacion.sch, analogico.sch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]
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2018-11-28 ESQ: cambios en net-tie y footprints PCB: cambios grandes de dimensiones y ruteo
    [Comunicacion.sch, fuentesLDO.sch, vop24_lpcxpresso1769_basehw.kicad_pcb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]
2018-11-29 ESQ: cambios menores PCB: finalizacion de ruteo con 0.3mm. Previo a poligonos
    [vop24_lpcxpresso1769_basehw.kicad_pcb, vop24_lpcxpresso1769_basehw.sch]
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
